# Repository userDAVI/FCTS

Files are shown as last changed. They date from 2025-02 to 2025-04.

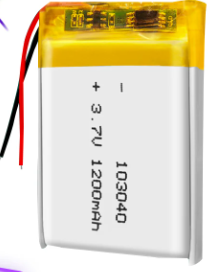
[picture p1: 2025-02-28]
Design das partes mecânicas/bateria.png

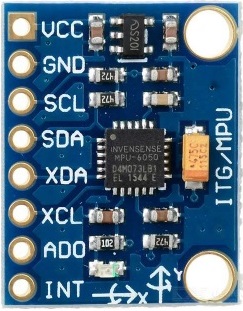
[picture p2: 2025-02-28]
Design das partes mecânicas/MPU-6050.jpg

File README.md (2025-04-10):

# Sistema Inercial para Análise de Marcha

Esse repositório aloca os arquivos de firmware e hardware eletrônico do projeto Análise inercial de centro de massa de pessoas com sindrome de Down.
O projeto foi financiado pela FAP-DF sob o EDITAL FAPDF 009/2023-DEMANDA ESPONTÂNEA, orientado pela prof. Dra. Cláudia Ochoa, professora de Engenharia Eletrônica da Faculdade de Ciências e Tecnologias em Engenharia (FCTE)- Campus UnB Gama.

O projeto tem em vista a quantificação e avaliação de simetria em marcha humana a partir da medição de trajetória do centro
de massa corporal utilizando sensores inerciais.

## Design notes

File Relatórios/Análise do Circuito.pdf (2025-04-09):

# ESTUDO DO ESQUEMÁTICO

CIRCUITO BÁSICO DA ESP
Capacitores de desacoplamento são utilizados para:
- Filtrar sinais de alta frequência, como ruídos.
- Garantir um fornecimento estável de energia.
- Manter uma tensão constante nos pinos de alimentação/terra de um CI.

Os capacitores de desacoplamento não alteram a tensão recebida pelo CI, apenas ajudam a filtrar ruídos e estabilizar a alimentação. Um capacitor eletrolítico (10 µF – 100 µF) remove ruídos de baixa frequência, já um cerâmico (0,1 µF – 1 µF) lida com ruídos de alta frequência. Isso garante filtragem eficiente para diferentes tipos de ruídos e mantém a tensão mais estável.

No circuito básico da ESP foi utilizado um capacitor de 22 µF que atua como um reservatório de carga para compensar variações de corrente mais lentas e de baixa frequência e um capacitor de 0.1 µF que filtra ruídos de alta frequência atuando como um curto-circuito para sinais indesejados, evitando que se propaguem pela alimentação.

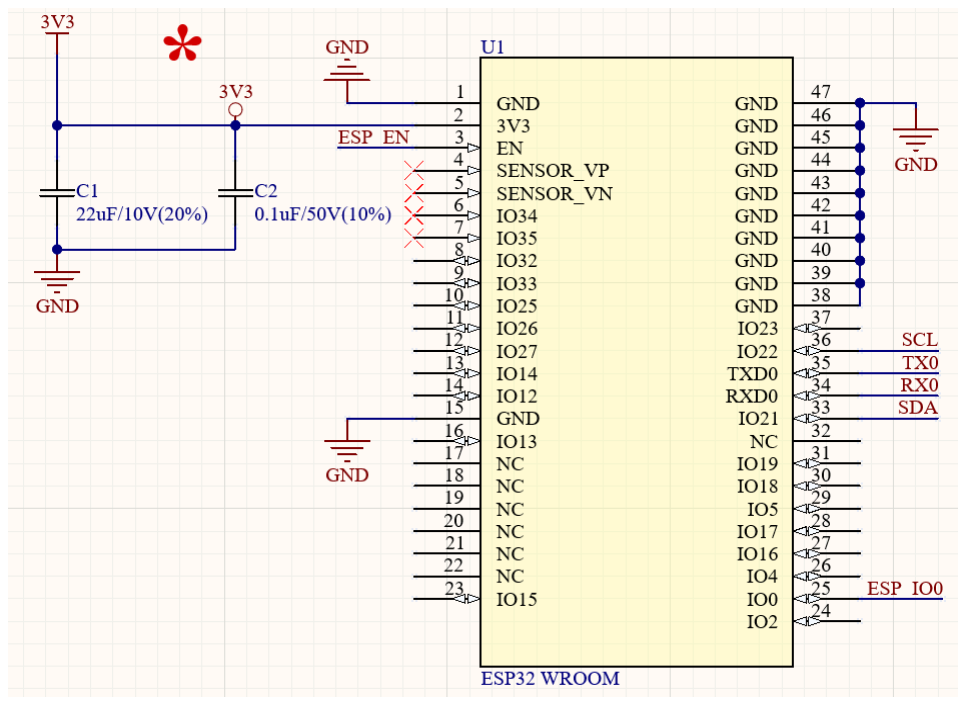
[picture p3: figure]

ESP-WROOM-32E
Foram utilizados os sinais: ESP_EN(enable), ESP_IO0 (modo de boot), SCL(sinal do clock),

TX0(transmissor 0), RX0(receptor 0), SDA(sinal de dados) e as conexões de GND.
Os sinais de SDA E SCL estão ligados ao MPU-6050.
Não pode ter plano de GND abaixo da antena da ESP!

CONECTORES
J1: para programação da esp. O tx e rx dos conectores vão para a esp.
J2: para alimentação.
USB4215-03-A_REVA: Conector USB tipo C, para carregamento da bateria. Possui conexões vcc e gnd.

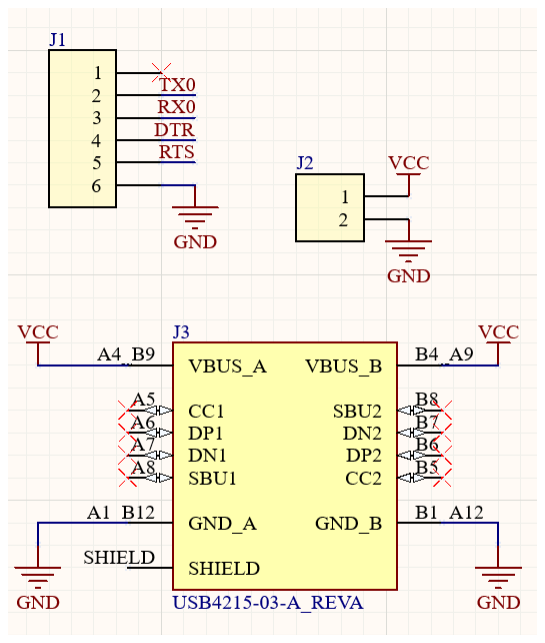
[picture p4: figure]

REGULADOR DE TENSÃO

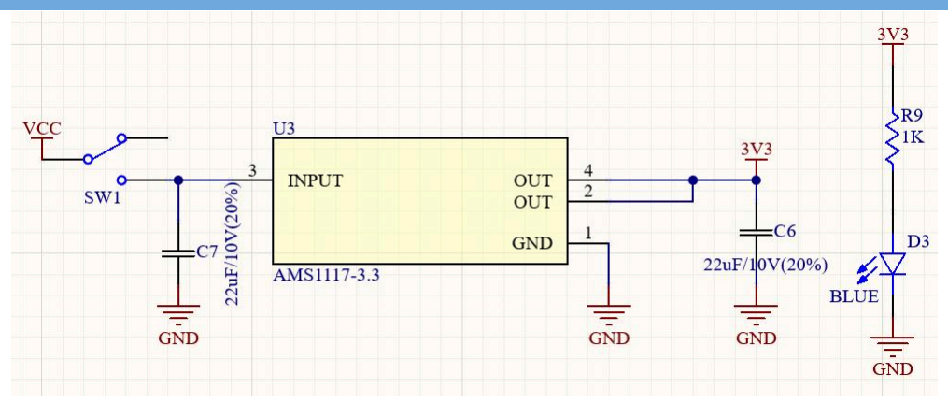
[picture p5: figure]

Componentes: Um switch que liga e desliga. Quando fechado, permite que a tensão VCC chegue ao regulador AMS1117-3.3. Quando aberto, corta a alimentação.
Dois capacitores de 22 µF que atuam como filtros.

Regulador AMS1117-3.3 converte o VCC para 3,3V.
Um LED que indica que o circuito está ligado e um Resistor que limita a corrente do LED.

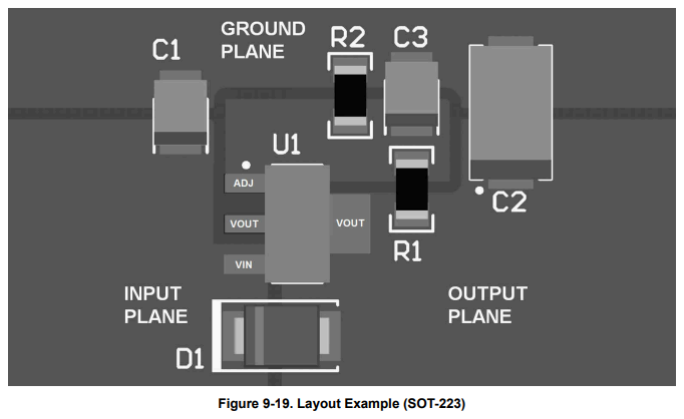
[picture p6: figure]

DOWNLOAD AUTOMÁTICO DO FIRMWARE
O circuito facilita a programação da ESP32 sem a necessidade de pressionar manualmente os botões de BOOT e RESET.

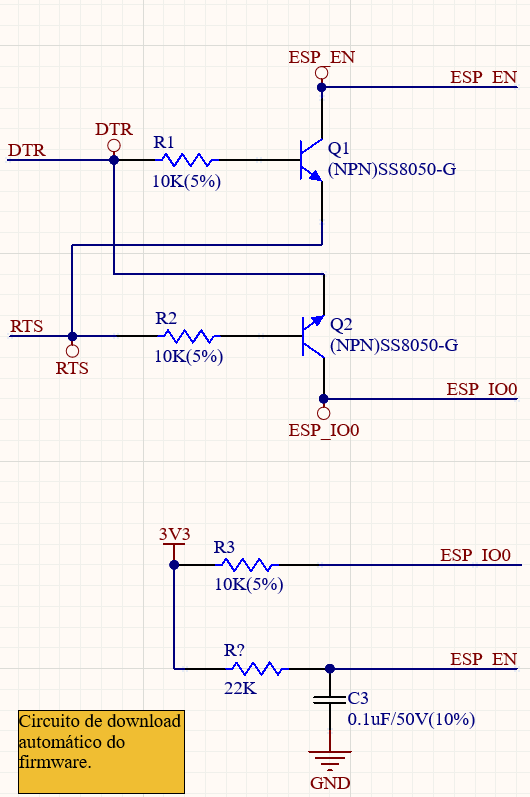
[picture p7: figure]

Transistor NPN: é um dispositivo semicondutor que amplifica e chaveia sinais elétricos.
Q1 e Q2 atuam como chaves controladas pelos sinais DTR (Data Terminal Ready) e RTS (Request to Send) da interface serial. Q1 controla ESP_EN (enable da ESP32).
Q2 controla ESP_IO0 (modo de boot para download do firmware).

Resistores R1 e R2 (10kΩ)
Limitam a corrente para os transistores Q1 e Q2, garantindo um acionamento adequado.

Resistores R3 (10kΩ) e R? (22kΩ)
R3 mantém ESP_IO0 em nível alto por padrão, garantindo que o ESP32 funcione normalmente quando não está em modo de programação.

R? (não deveria ser R4) junto ao capacitor C3 ajuda na estabilidade do sinal de ESP_EN, evitando resets indesejados.

Capacitor C3 (0,1µF/50V)
Atua como filtro para evitar oscilações na corrente ao resetar a ESP32.
Função dos sinais:
ESP_IO0:
- Execução do Código: Se o ESP_IO0 estiver em nível alto durante o reset, a ESP32 inicia normalmente e executa o firmware já gravado.
- Gravação de Firmware: Se o ESP_IO0 estiver em nível baixo durante o reset, a ESP32 entra no modo de programação para receber um novo firmware.

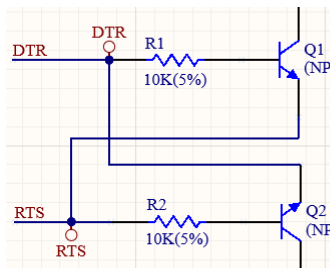
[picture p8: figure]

Como funciona esse laço nos transistores? Essa conexão cruzada garante que os dois sinais sejam ativados no momento certo e possuam o mesmo nível lógico (0 ou 1).

MPU-6050
É um sensor que combina um acelerômetro e um giroscópio, permitindo a detecção de movimento e orientação. Captura de canais X, Y e Z ao mesmo tempo.

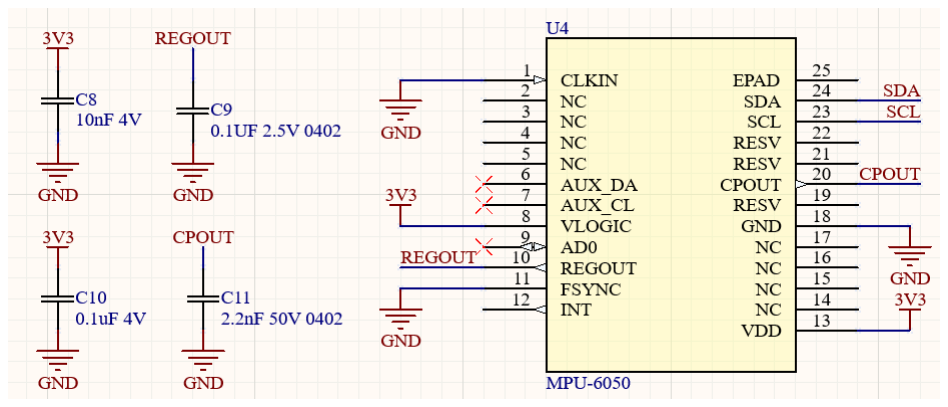
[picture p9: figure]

REGOUT e CPOUT são siglas que geralmente se referem a saídas de reguladores de tensão ou de circuitos de filtragem.
O sensor se comunica com a ESP32 através de comunicação I2C.

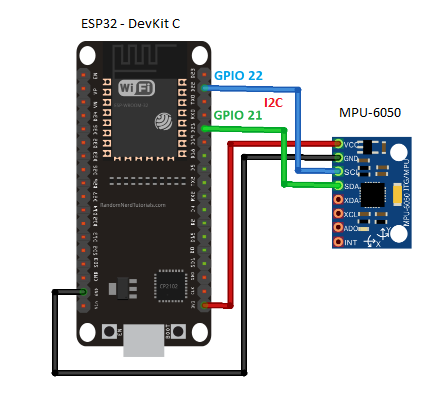
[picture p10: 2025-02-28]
Design das partes mecânicas/conexions.png

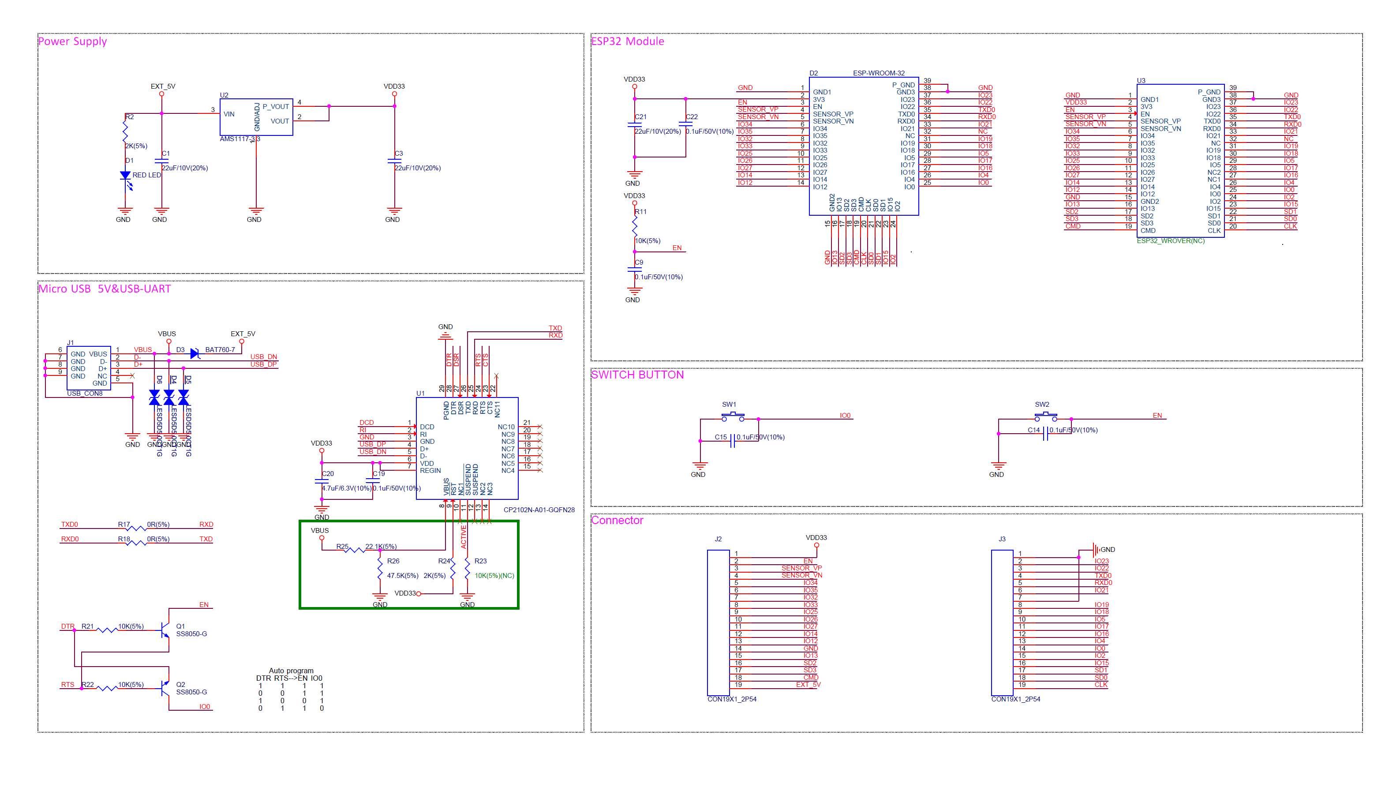
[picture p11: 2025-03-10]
Hardware/Documentos adicionais/ESP32-DEVKIT-V4-diagrama.jpg

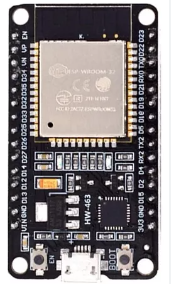
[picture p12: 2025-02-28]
Design das partes mecânicas/ESP32.png

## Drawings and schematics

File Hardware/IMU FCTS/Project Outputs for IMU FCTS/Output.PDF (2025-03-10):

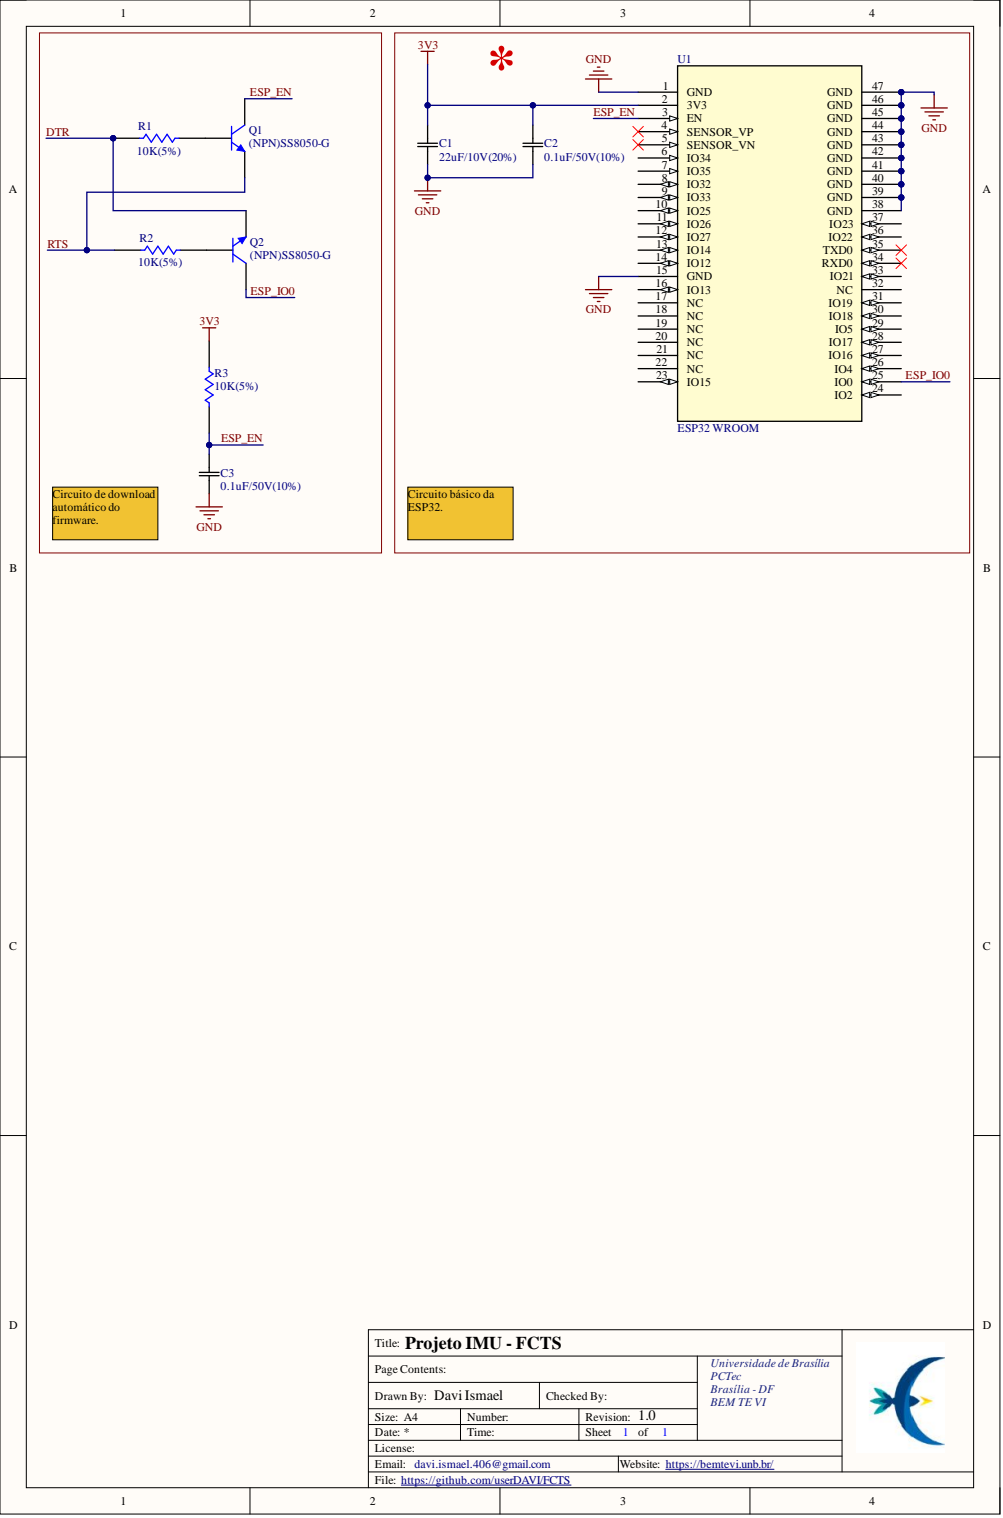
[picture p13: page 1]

Page Co n ten t s : | Un ivers i d a de de B r a s íl i a PCTe c B r a s í l i a -D F B EM TE VI

Draw n By : Da vi Isma e l | Checked By :
Size : A 4 | N umb er : | 1 . 0 Rev i s i o n :
Dat e : | T ime : | Shee t 1 o f 1

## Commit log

2025-02-28 Criação das partes do projeto
    Foi adicionado ao diretório as pastas de firmware, hardware e partes mecânicas.
    Foram criados os templates iniciais para o firmware e hardware.
    [Esquematico.SchDoc, Hadware do medidor de centro de massa.PrjPcb, Layout.PcbDoc]
2025-02-28 Add folder
    adicionando imagens na pasta de desenhos mecânicos
2025-03-05 Update README.md
    Atualização de texto.
2025-03-05 Modificações no hardware
    Inclusão de template e criação da biblioteca
    [Esquematico.SchDoc, Layout.PcbDoc, PcbLib1.PcbLib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]
2025-03-10 Atualização de hardware
    Adição de componentes do esquemático
    [Esquematico.SchDoc, Hadware do medidor de centro de massa.PrjPcb, IMU FCTS.PrjPcb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]
2025-03-14 Finalização da placa
    up do projeto finalizado
    [IMU FCTS.PrjPcb, Main.SchDoc, PCB1.PcbDoc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]
2025-03-17 Circuito de carga
    Retirada do CI
    [Main.SchDoc]
2025-03-19 atualização hardware
    mudei o circuito de download automático do firmware
    [Main.SchDoc]
2025-04-03 Alterações no hardware
    Feito annotation
    [Main.SchDoc, PcbLib1.PcbLib, Schlib1.SchLib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]
2025-04-09 Upload documento de análise do esquemático
2025-04-10 Atualização do título
    Mudança de "FCTS" para "Sistema Inercial para Análise de Marcha."
